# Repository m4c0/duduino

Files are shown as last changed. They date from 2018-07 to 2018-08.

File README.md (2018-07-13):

# duduino

My own version of an Arduino-compatible board, with focus in SPI and IIC.

## Why another Arduino?

First and foremost, I'm not trying to "reinvent" or "improve" Arduino. I'm doing a lot of
experiments at home with "vanilla" Arduino. There may be some limitations, but usually it
is quite simple and fast to prototype.

Curiously, I don't need many GPIO ports - I interface using SPI or IIC, and that's it. So
all GPIOs are just hanging in there, doing nothing. Also, since some of those experiments
will be on my desk for a long time, it looks wasteful to leave Arduinos everywhere with
dupont cables (and I'm too lazy to rewire everything over and over when I do different
prototypes).

Therefore, I decided to design and solder my own boards, to fulfill my own requirements.
Since Arduino is Open-Source, I thought it's my duty to get my own Arduino and release it
as Open Source as well.

## Features

* Compatible with Arduino bootloaders
* Plug-and-play integration with FTDI USB-to-serial, AVRKit pins and IIC OLEDs
* SCL and SDA has stronger pull-ups
* Powered by USB (5V)
* Works at 3.3V (to avoid burning some OLEDs and FPGAs :)

## Limitations

* GPIOs are not exposed (except the ones for serial, SPI and IIC)
* Current version is THT, so the board is huge

## Things that may be added

* Powered by LiPo batteries. This depends if there'll be space left in the board

## Revision History

### Version v0.1 (in development)

* First release
* Contains:
  * USB connector
  * 8MHz crystal
  * LM3940 3.3V regulator
  * Inline pins for FTDI USB-to-Serial
  * Inline pins for IIC OLEDs
  * AVR-compatible SPI header
  * And the classic GPIO-13 LED

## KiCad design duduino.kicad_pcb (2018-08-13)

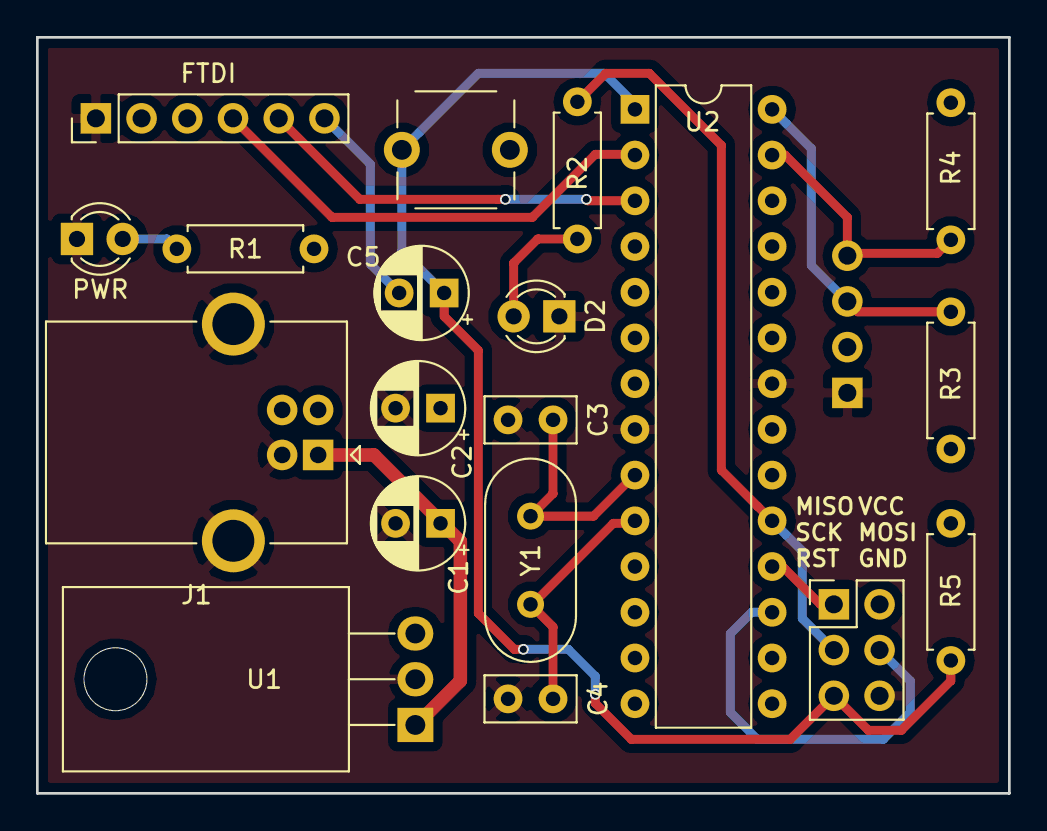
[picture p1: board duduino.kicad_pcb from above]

Board: 2 copper layers, 54.0 x 42.0 mm, 20 parts (1 on the bottom side), 16 nets.

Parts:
C1: 0.47u; CP_Radial_D5.0mm_P2.50mm
C2: 33u; CP_Radial_D5.0mm_P2.50mm
C3, C4: 22p; C_Disc_D5.0mm_W2.5mm_P2.50mm
C5: 100n; CP_Radial_D5.0mm_P2.50mm
D1: PWR; LED_D3.0mm
D2: LED; LED_D3.0mm
J1: USB_B; USB_B_OST_USB-B1HSxx_Horizontal
J2: FTDI; PinHeader_1x06_P2.54mm_Vertical
J3: IIC; SPI-OLED
J4: AVRKit; PinHeader_2x03_P2.54mm_Vertical
R1, R2: 220; R_Axial_DIN0207_L6.3mm_D2.5mm_P7.62mm_Horizontal
R3, R4, R5: 10k; R_Axial_DIN0207_L6.3mm_D2.5mm_P7.62mm_Horizontal
SW1: RESET; SW_PUSH_6mm
U1: LM3940_TO220; TO-220-3_Horizontal_TabDown
U2: ATMEGA168-20PU; DIP-28_W7.62mm
Y1: Crystal; Crystal_HC18-U_Vertical

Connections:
+3V3: C2.1, J2.3, J3.2, J4.2, R1.2, R3.2, R4.2, R5.1, SW1.2, U1.3, U2.7, U2.20, U2.21
+5V: C1.1, J1.1, U1.1
/DTR: C5.2, J2.6
/I2C_SCL: J3.3, R3.1, U2.28
/I2C_SDA: J3.4, R4.1, U2.27
/MISO: J4.1, U2.18
/MOSI: J4.4, U2.17
/RST: C5.1, J4.5, R5.2, SW1.1, U2.1
/RXD: J2.4, U2.2
/SCK: J4.3, R2.2, U2.19
/TXD: J2.5, U2.3
/XTAL1: C3.1, U2.9, Y1.1
/XTAL2: C4.1, U2.10, Y1.2
GND: C1.2, C2.2, C3.2, C4.2, D1.1, D2.1, J1.4, J1.5, J2.1, J3.1, J4.6, U1.2, U2.8, U2.22
unnamed: D1.2, R1.1
unnamed: D2.2, R2.1

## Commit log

2018-07-13 added stubs for KiCAD + some thoughts on README
    [duduino.kicad_pcb, duduino.sch]
2018-07-13 first schematic
    [duduino.sch]
2018-07-18 assigning netlist and such
    [duduino.sch]
2018-07-18 playing around the layout of the pcb
    [duduino.kicad_pcb]
2018-08-13 tweaking the layout, upgrading Kicad, crying a little bit, then wiring all the PCB
    [duduino.kicad_pcb, duduino.sch]
